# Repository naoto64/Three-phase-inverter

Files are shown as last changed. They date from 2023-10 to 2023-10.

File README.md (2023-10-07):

# Three-phase-inverter
Three-phase inverter operating at AC100V.
Inverter inverter image
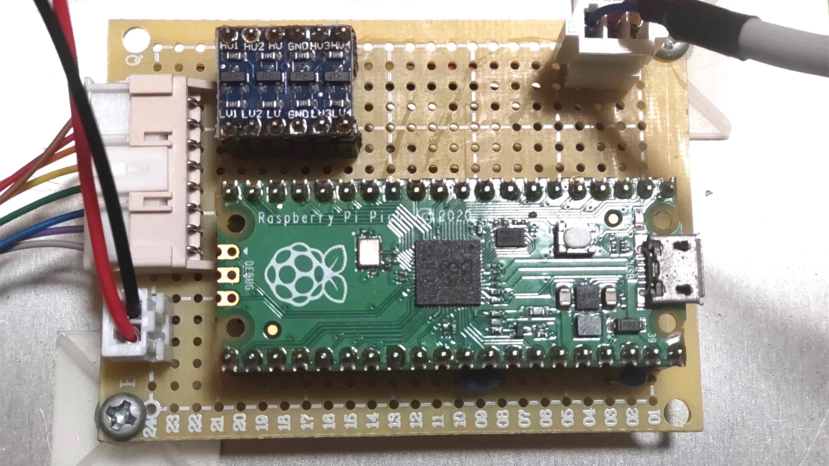
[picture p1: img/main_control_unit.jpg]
Main Control Unit main contorol unit image

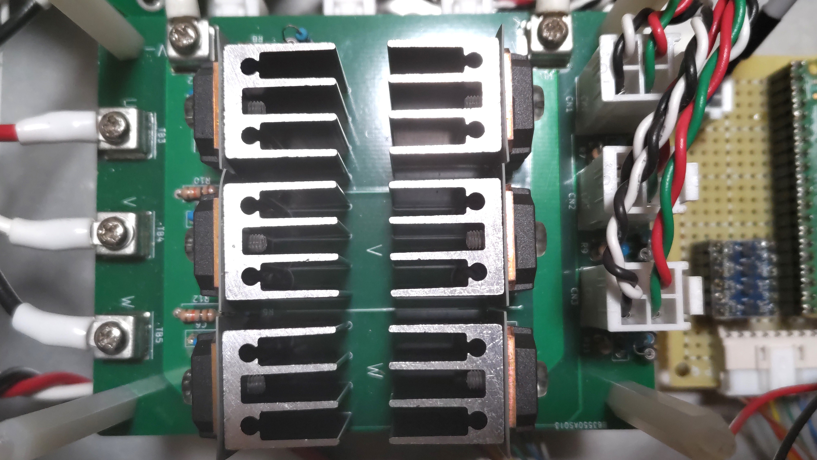
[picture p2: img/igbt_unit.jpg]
IGBT unit igbt unit image

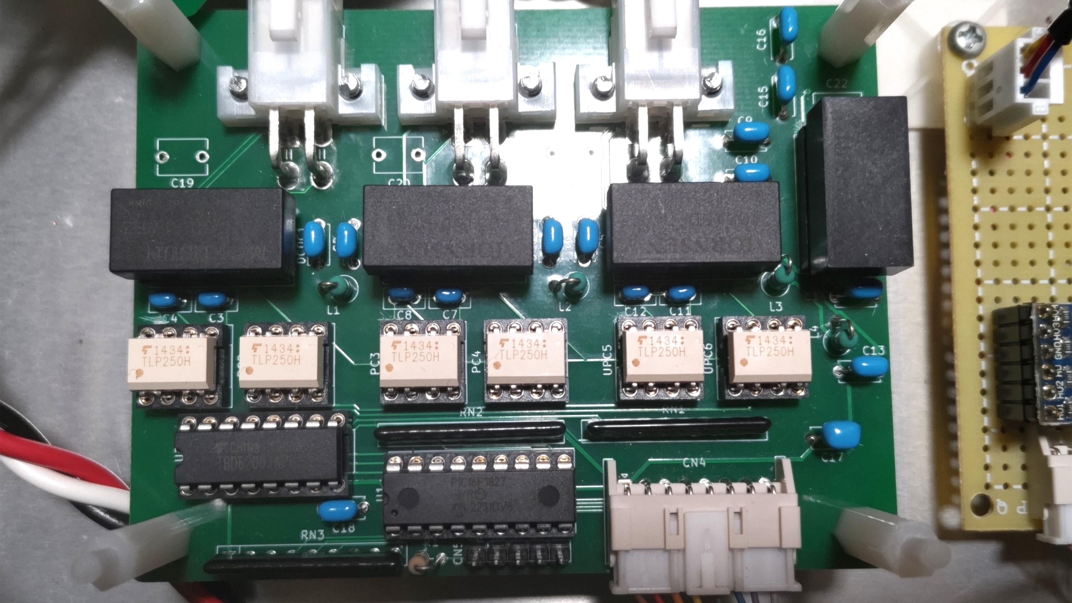
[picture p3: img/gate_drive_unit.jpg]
Gate Drive Unit gate_drive unit image

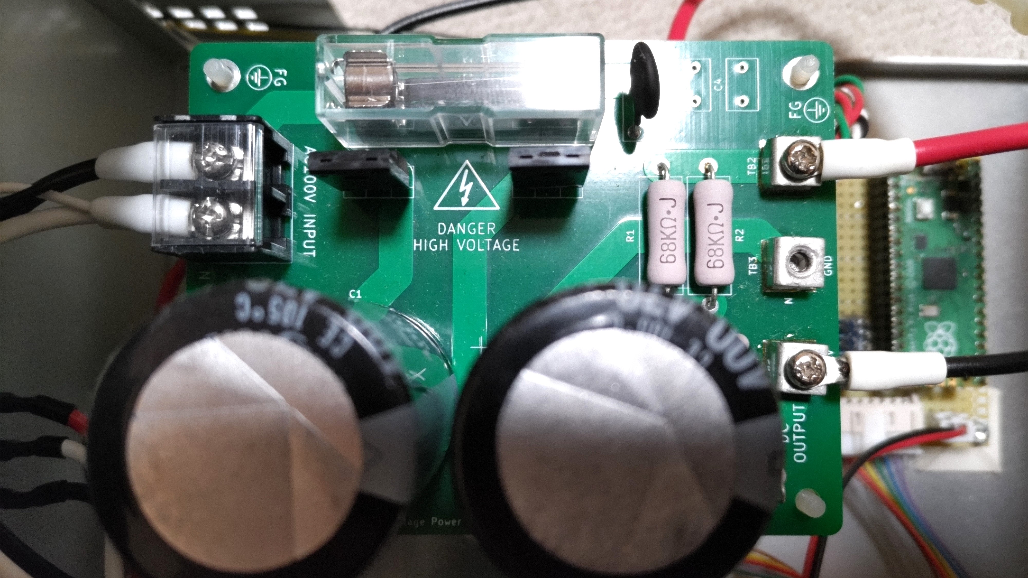
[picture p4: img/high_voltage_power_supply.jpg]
High Voltage Power Supply main contorol unit image


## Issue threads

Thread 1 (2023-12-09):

Change IGBT to other Manufacturer

bca759577, 2023-12-09:
Can I Change IGBT to Toshiba GT50J341?
I compared it and found that the specifications of the two IGBTs are similar.
But the Current Collector of GT50J341 is slightly higher. (GT50J341=50A  RJH60D0DPK=45A)

naoto64, 2023-12-09:
Since it says Dedicated to Current-Resonant Inverter, I cannot recommend it, but I think it can be replaced because the characteristics themselves are almost the same.
However, when replacing, it is necessary to change R1 to R6 of igbt_module to 39Ω.

Closed 2023-12-10.

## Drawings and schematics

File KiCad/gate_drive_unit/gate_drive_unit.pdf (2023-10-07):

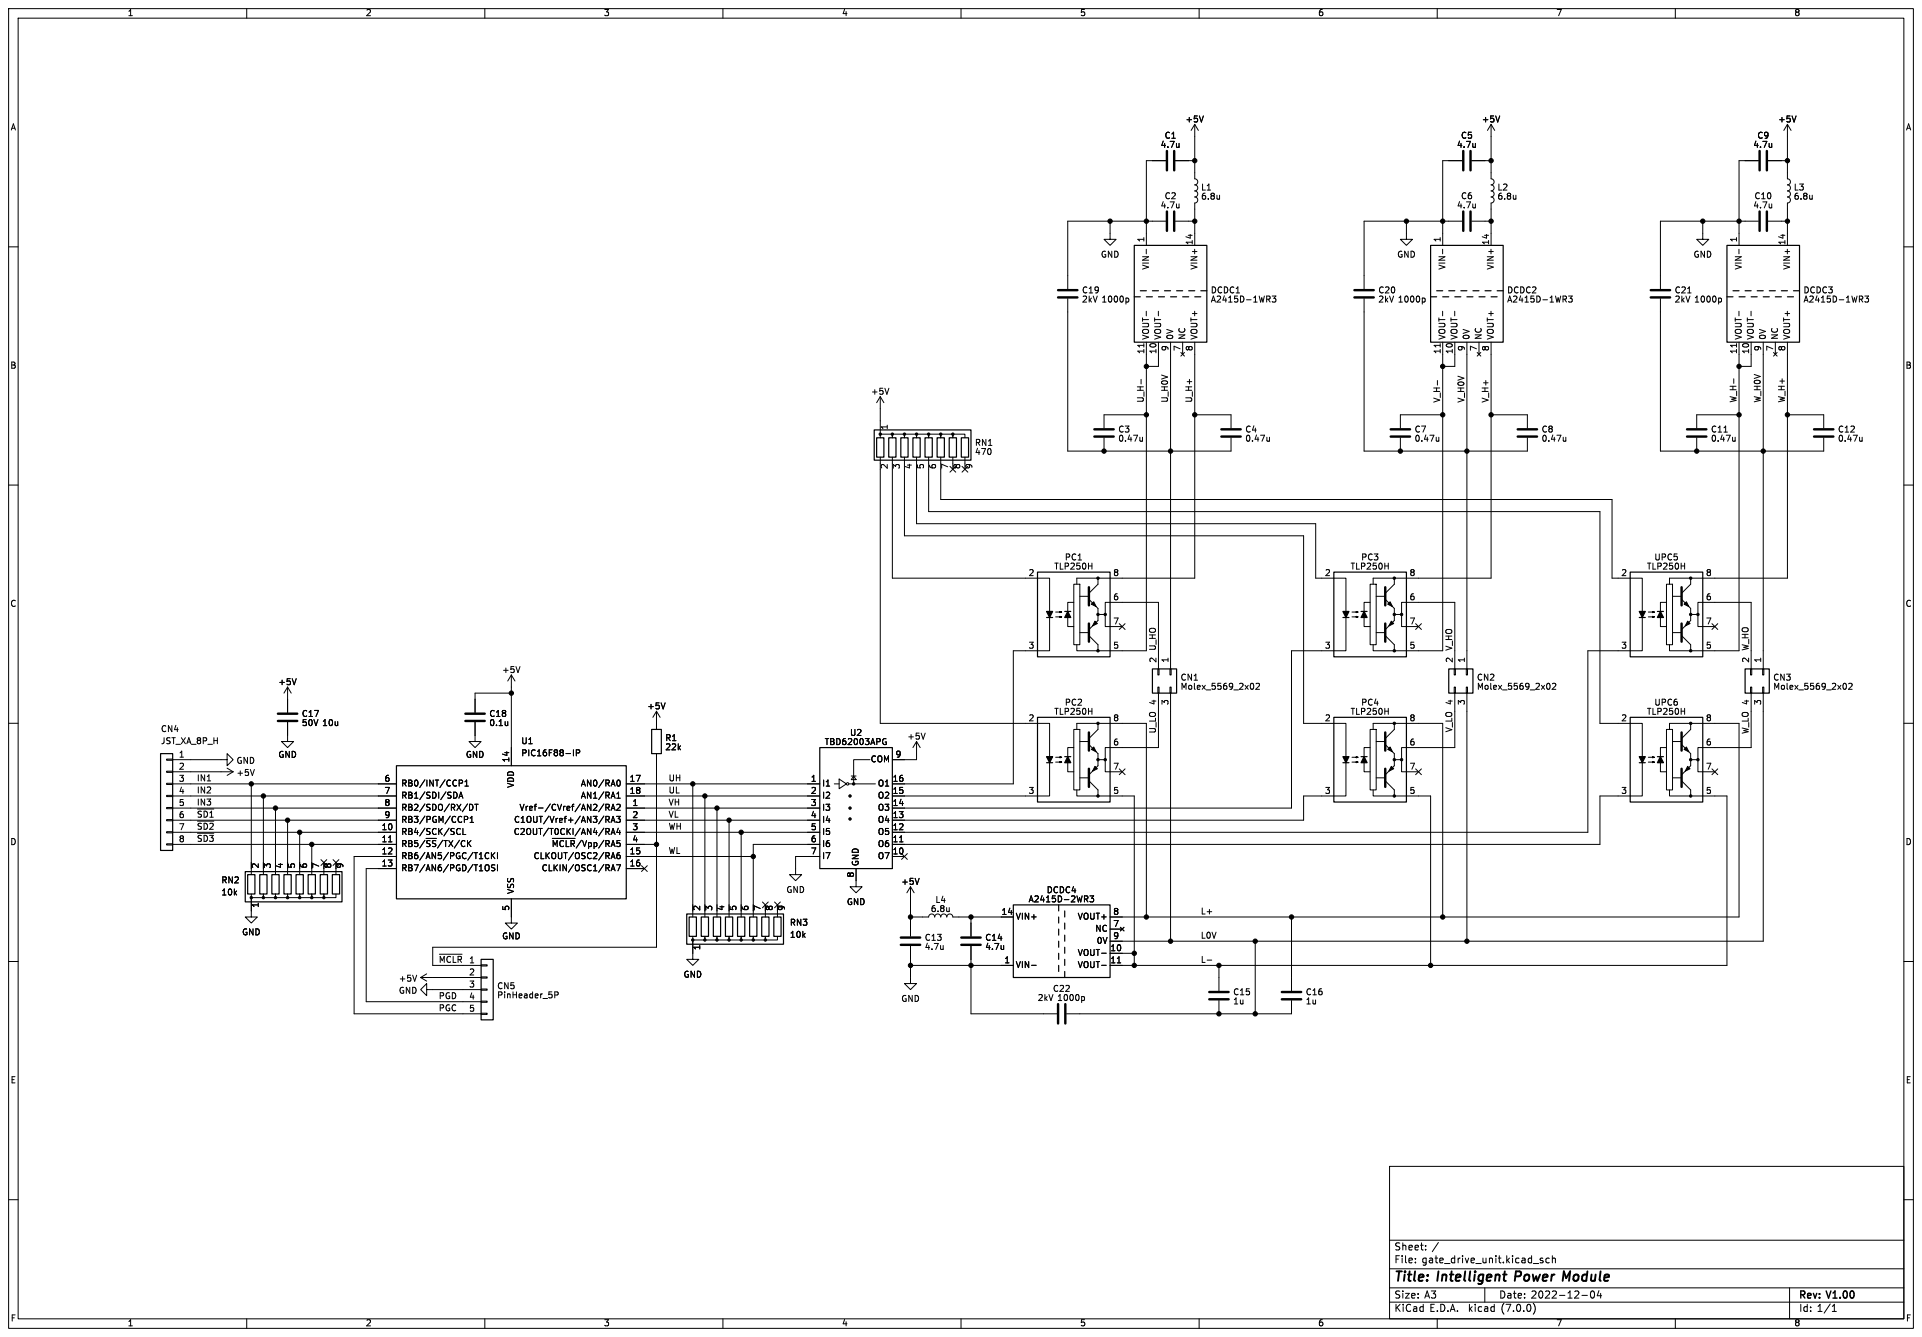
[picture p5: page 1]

3 CN2 Molex_5569_2x02 VIN- 1 VOUT- 10 VOUT- 11 VIN+ 14 NC

5 RB0/INT/CCP1 6 RB1/SDI/SDA 7 RB2/SDO/RX/DT 8 RB3/PGM/CCP1 9 U1PIC16F88-IP U_H0V U_H+ W_H+

5 RB0/INT/CCP1 6 RB1/SDI/SDA 7 RB2/SDO/RX/DT 8 RB3/PGM/CCP1 9 +5V R1

File: gate_drive_unit.kicad_sch Sheet: /
Id: 1/1 Title: Intelligent Power Module

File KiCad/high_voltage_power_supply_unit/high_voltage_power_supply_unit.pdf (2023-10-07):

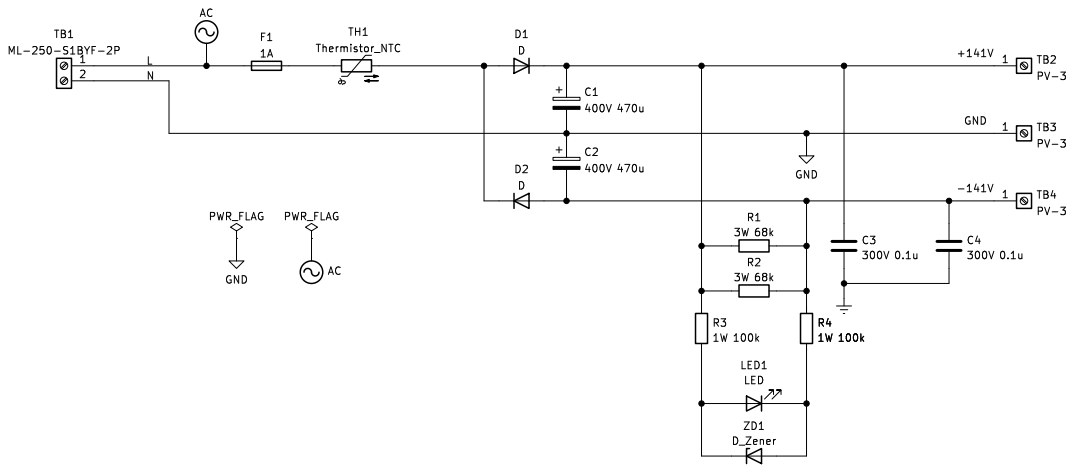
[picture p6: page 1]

Id: 1/1 Title: High Voltage Power Supply Unit File: high_voltage_power_supply_unit.kicad_sch Sheet: / PWR_FLAG

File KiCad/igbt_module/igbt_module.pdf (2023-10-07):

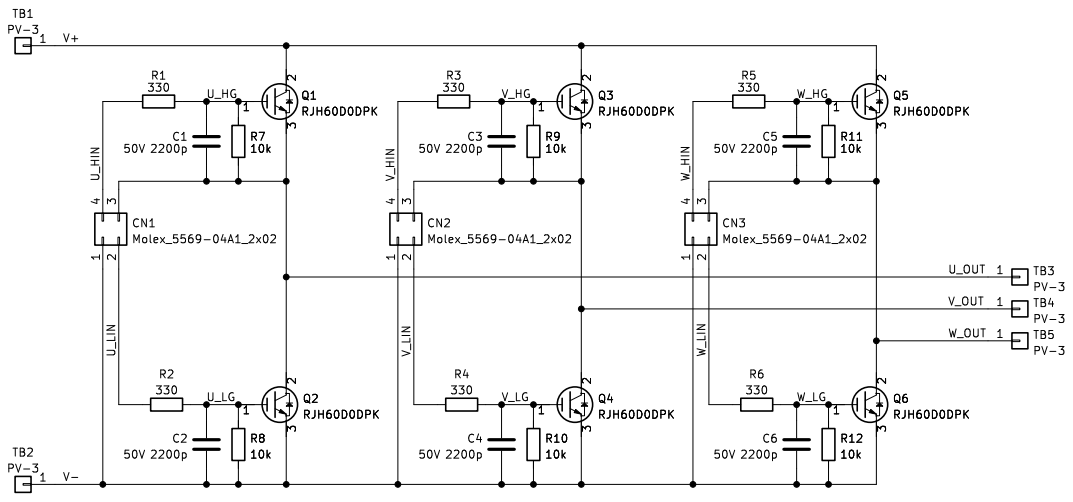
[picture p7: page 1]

Id: 1/1 Title: IGBT Module

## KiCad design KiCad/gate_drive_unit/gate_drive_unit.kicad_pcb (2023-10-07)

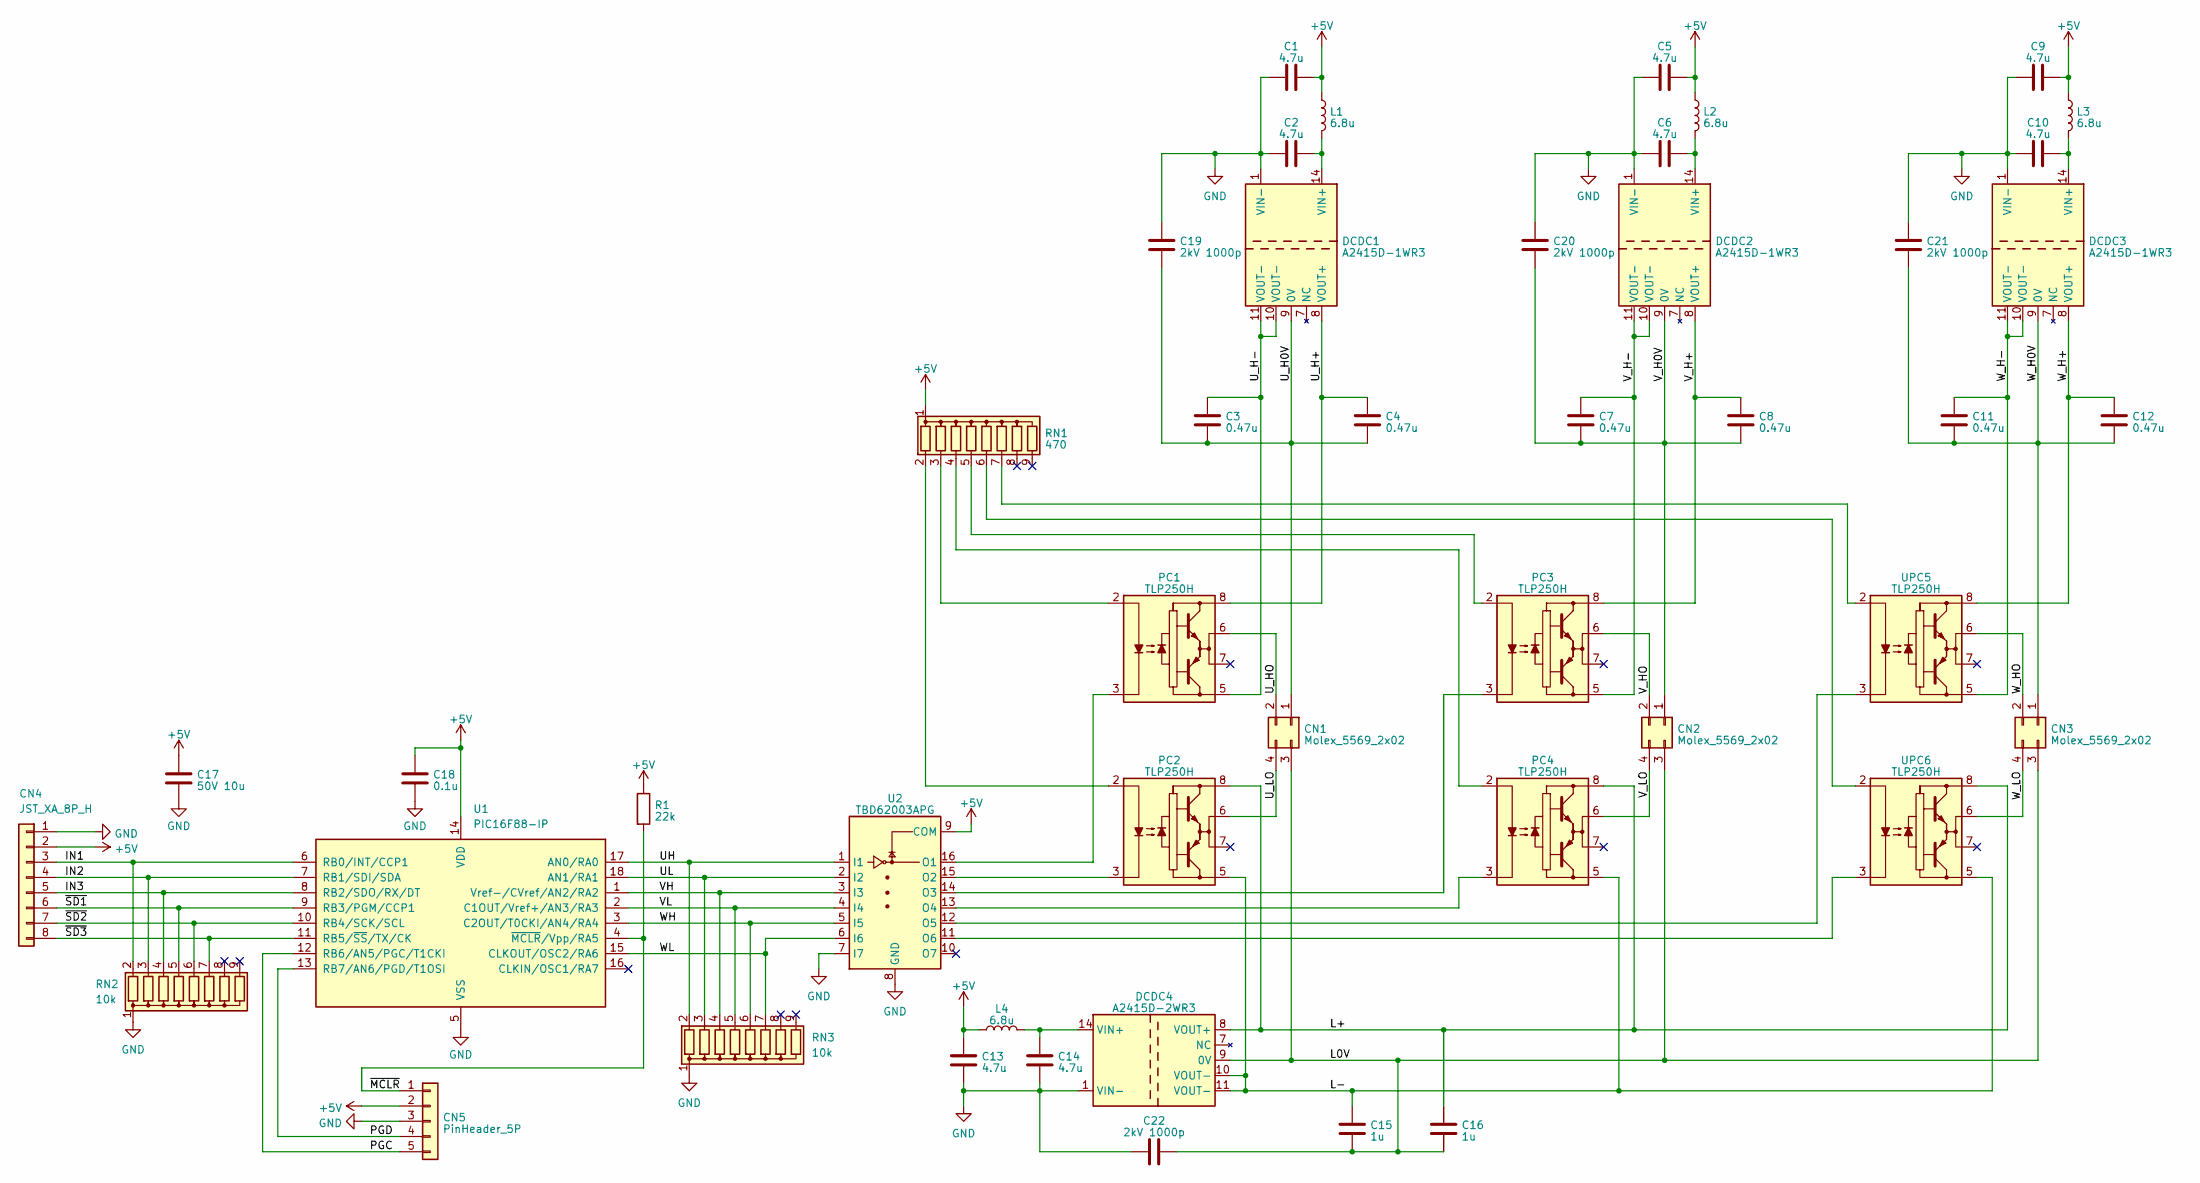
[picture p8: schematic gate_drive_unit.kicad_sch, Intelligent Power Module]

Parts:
C1, C2, C5, C6, C9, C10, C13, C14: 4.7u; C_Disc_D5.0mm_W2.5mm_P5.00mm
C3, C4, C7, C8, C11, C12: 0.47u; C_Disc_D5.0mm_W2.5mm_P2.50mm
C15, C16: 1u; C_Disc_D5.0mm_W2.5mm_P5.00mm
C17: 50V 10u; C_Disc_D5.0mm_W2.5mm_P5.00mm
C18: 0.1u; C_Disc_D5.0mm_W2.5mm_P5.00mm
C19, C20, C21, C22: 2kV 1000p; C_Disc_D6.0mm_W4.4mm_P5.00mm
CN1, CN2, CN3: Molex_5569_2x02; Molex_Mini-Fit_Jr_5569-04A1_2x02_P4.20mm_Horizontal
CN4: JST_XA_8P_H; JST_XA_S08B-XASK-1N-BN_1x08_P2.50mm_Horizontal
CN5: PinHeader_5P; PinHeader_1x05_P2.54mm_Vertical
DCDC1, DCDC2, DCDC3: A2415D-1WR3; DIP-14_W7.62mm_Socket
DCDC4: A2415D-2WR3; DIP-14_W7.62mm_Socket
L1, L2, L3, L4: 6.8u; L_Axial_L7.0mm_D3.3mm_P2.54mm_Vertical_Fastron_MICC
PC1, PC2, PC3, PC4: TLP250H; DIP-8_W7.62mm_Socket
R1: 22k; R_Axial_DIN0204_L3.6mm_D1.6mm_P2.54mm_Vertical
RN1: 470; R_Array_SIP9
RN2, RN3: 10k; R_Array_SIP9
U1: PIC16F88-IP; DIP-18_W7.62mm_Socket
U2: TBD62003APG; DIP-16_W7.62mm
UPC5, UPC6: TLP250H; DIP-8_W7.62mm_Socket

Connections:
+5V: C1.2, C5.2, C9.2, C13.1, C17.1, C18.1, CN4.2, CN5.2, L1.1, L2.1, L3.1, L4.1, R1.1, RN1.1 (common), U1.14 (VDD), U2.9 (COM)
/IN1: CN4.3, RN2.2 (R1), U1.6 (RB0/INT/CCP1)
/IN2: CN4.4, RN2.3 (R2), U1.7 (RB1/SDI/SDA)
/IN3: CN4.5, RN2.4 (R3), U1.8 (RB2/SDO/RX/DT)
/L0V: C15.2, C16.1, C22.1, CN1.3, CN2.3, CN3.3, DCDC4.9 (0V)
/L+: C16.2, DCDC4.8 (VOUT+), PC2.8 (VCC), PC4.8 (VCC), UPC6.8 (VCC)
/L-: C15.1, DCDC4.10 (VOUT-), DCDC4.11 (VOUT-), PC2.5 (VEE), PC4.5 (VEE), UPC6.5 (VEE)
/PGC: CN5.5, U1.12 (RB6/AN5/PGC/T1CKI)
/PGD: CN5.4, U1.13 (RB7/AN6/PGD/T1OSI)
/UH: RN3.2 (R1), U1.17 (AN0/RA0), U2.1 (I1)
/UL: RN3.3 (R2), U1.18 (AN1/RA1), U2.2 (I2)
/U_H0V: C3.2, C4.1, C19.2, CN1.1, DCDC1.9 (0V)
/U_H+: C4.2, DCDC1.8 (VOUT+), PC1.8 (VCC)
/U_H-: C3.1, DCDC1.10 (VOUT-), DCDC1.11 (VOUT-), PC1.5 (VEE)
/U_HO: CN1.2, PC1.6 (VO)
/U_LO: CN1.4, PC2.6 (VO)
/VH: RN3.4 (R3), U1.1 (Vref-/CVref/AN2/RA2), U2.3 (I3)
/VL: RN3.5 (R4), U1.2 (C1OUT/Vref+/AN3/RA3), U2.4 (I4)
/V_H0V: C7.2, C8.1, C20.2, CN2.1, DCDC2.9 (0V)
/V_H+: C8.2, DCDC2.8 (VOUT+), PC3.8 (VCC)
/V_H-: C7.1, DCDC2.10 (VOUT-), DCDC2.11 (VOUT-), PC3.5 (VEE)
/V_HO: CN2.2, PC3.6 (VO)
/V_LO: CN2.4, PC4.6 (VO)
/WH: RN3.6 (R5), U1.3 (C2OUT/T0CKI/AN4/RA4), U2.5 (I5)
/WL: RN3.7 (R6), U1.15 (CLKOUT/OSC2/RA6), U2.6 (I6)
/W_H0V: C11.2, C12.1, C21.2, CN3.1, DCDC3.9 (0V)
/W_H+: C12.2, DCDC3.8 (VOUT+), UPC5.8 (VCC)
/W_H-: C11.1, DCDC3.10 (VOUT-), DCDC3.11 (VOUT-), UPC5.5 (VEE)
/W_HO: CN3.2, UPC5.6 (VO)
/W_LO: CN3.4, UPC6.6 (VO)
/~MCLR: CN5.1, R1.2, U1.4 (~MCLR/Vpp/RA5)
/~SD1: CN4.6, RN2.5 (R4), U1.9 (RB3/PGM/CCP1)
/~SD2: CN4.7, RN2.6 (R5), U1.10 (RB4/SCK/SCL)
/~SD3: CN4.8, RN2.7 (R6), U1.11 (RB5/~SS/TX/CK)
GND: C1.1, C2.1, C5.1, C6.1, C9.1, C10.1, C13.2, C14.2, C17.2, C18.2, C19.1, C20.1, C21.1, C22.2, CN4.1, CN5.3, DCDC1.1 (VIN-), DCDC2.1 (VIN-), DCDC3.1 (VIN-), DCDC4.1 (VIN-), RN2.1 (common), RN3.1 (common), U1.5 (VSS), U2.7 (I7), U2.8 (GND)
unnamed: C2.2, DCDC1.14 (VIN+), L1.2
unnamed: C6.2, DCDC2.14 (VIN+), L2.2
unnamed: C10.2, DCDC3.14 (VIN+), L3.2
unnamed: C14.1, DCDC4.14 (VIN+), L4.2
unnamed: PC1.2 (A), RN1.3 (R2)
unnamed: PC1.3 (C), U2.16 (O1)
unnamed: PC2.2 (A), RN1.2 (R1)
unnamed: PC2.3 (C), U2.15 (O2)
unnamed: PC3.2 (A), RN1.5 (R4)
unnamed: PC3.3 (C), U2.14 (O3)
unnamed: PC4.2 (A), RN1.4 (R3)
unnamed: PC4.3 (C), U2.13 (O4)
unnamed: RN1.6 (R5), UPC6.2 (A)
unnamed: RN1.7 (R6), UPC5.2 (A)
unnamed: U2.12 (O5), UPC5.3 (C)
unnamed: U2.11 (O6), UPC6.3 (C)

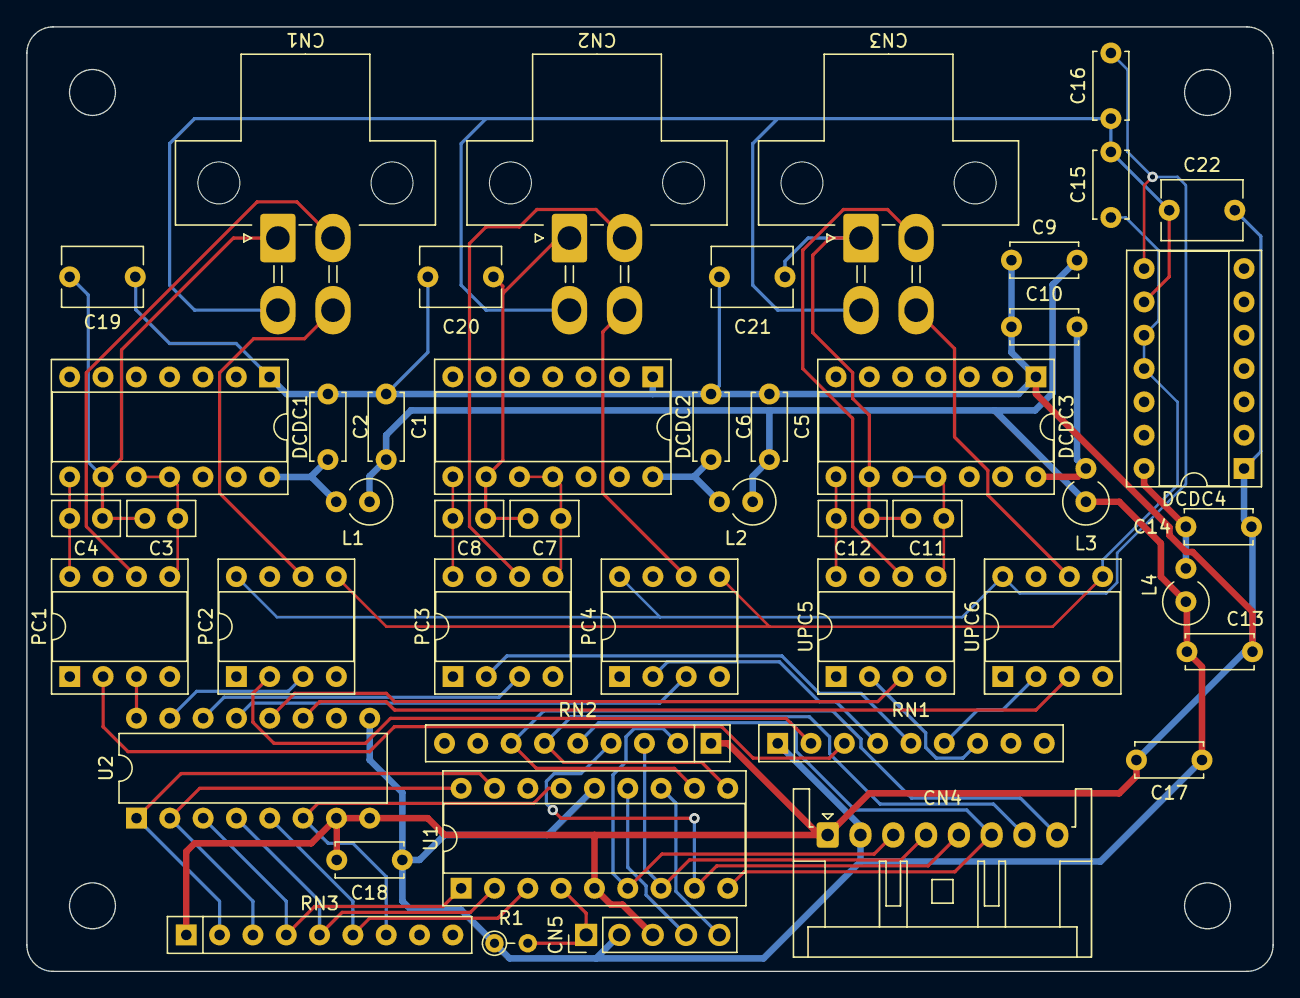
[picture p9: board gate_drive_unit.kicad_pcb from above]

Board: 2 copper layers, 95.0 x 72.0 mm, 47 parts (0 on the bottom side), 51 nets.

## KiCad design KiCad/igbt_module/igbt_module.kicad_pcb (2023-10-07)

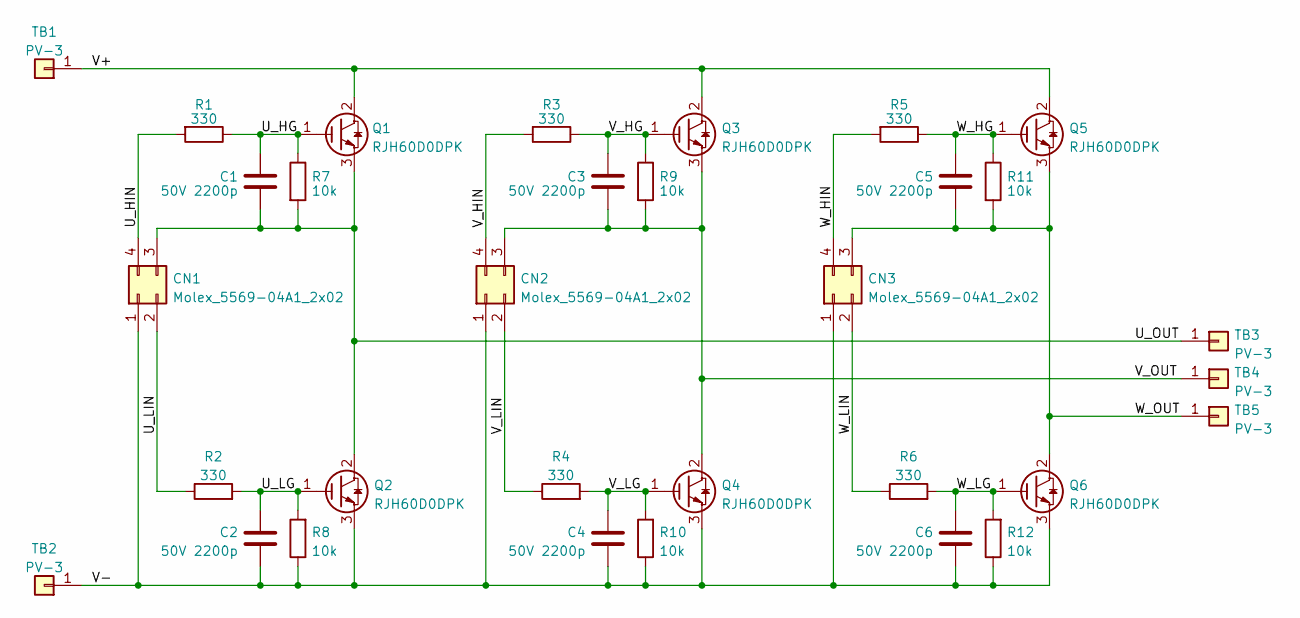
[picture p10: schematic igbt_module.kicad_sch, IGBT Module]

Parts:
C1, C2, C3, C4, C5, C6: 50V 2200p; C_Disc_D5.0mm_W2.5mm_P2.50mm
CN1, CN2, CN3: Molex_5569-04A1_2x02; Molex_Mini-Fit_Jr_5566-04A_2x02_P4.20mm_Vertical
Q1, Q2, Q3, Q4, Q5, Q6: RJH60D0DPK; TO-3P-3_Vertical
R1, R2, R3, R4, R5, R6: 330; R_Axial_DIN0204_L3.6mm_D1.6mm_P2.54mm_Vertical
R7, R9, R11: 10k; R_Axial_DIN0204_L3.6mm_D1.6mm_P2.54mm_Vertical
R8, R10, R12: 10k; R_Axial_DIN0207_L6.3mm_D2.5mm_P7.62mm_Horizontal
TB1, TB2: PV-3
TB3, TB4, TB5: PV-3; PV-3_Both

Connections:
/U_HG: C1.1, Q1.1 (G), R1.1, R7.1
/U_HIN: CN1.4, R1.2
/U_LG: C2.2, Q2.1 (G), R2.2, R8.2
/U_LIN: CN1.2, R2.1
/U_OUT: C1.2, CN1.3, Q1.3 (E), Q2.2 (C), R7.2, TB3.1
/V+: Q1.2 (C), Q3.2 (C), Q5.2 (C), TB1.1
/V-: C2.1, C4.1, C6.1, CN1.1, CN2.1, CN3.1, Q2.3 (E), Q4.3 (E), Q6.3 (E), R8.1, R10.1, R12.1, TB2.1
/V_HG: C3.1, Q3.1 (G), R3.1, R9.1
/V_HIN: CN2.4, R3.2
/V_LG: C4.2, Q4.1 (G), R4.2, R10.2
/V_LIN: CN2.2, R4.1
/V_OUT: C3.2, CN2.3, Q3.3 (E), Q4.2 (C), R9.2, TB4.1
/W_HG: C5.1, Q5.1 (G), R5.1, R11.1
/W_HIN: CN3.4, R5.2
/W_LG: C6.2, Q6.1 (G), R6.2, R12.2
/W_LIN: CN3.2, R6.1
/W_OUT: C5.2, CN3.3, Q5.3 (E), Q6.2 (C), R11.2, TB5.1

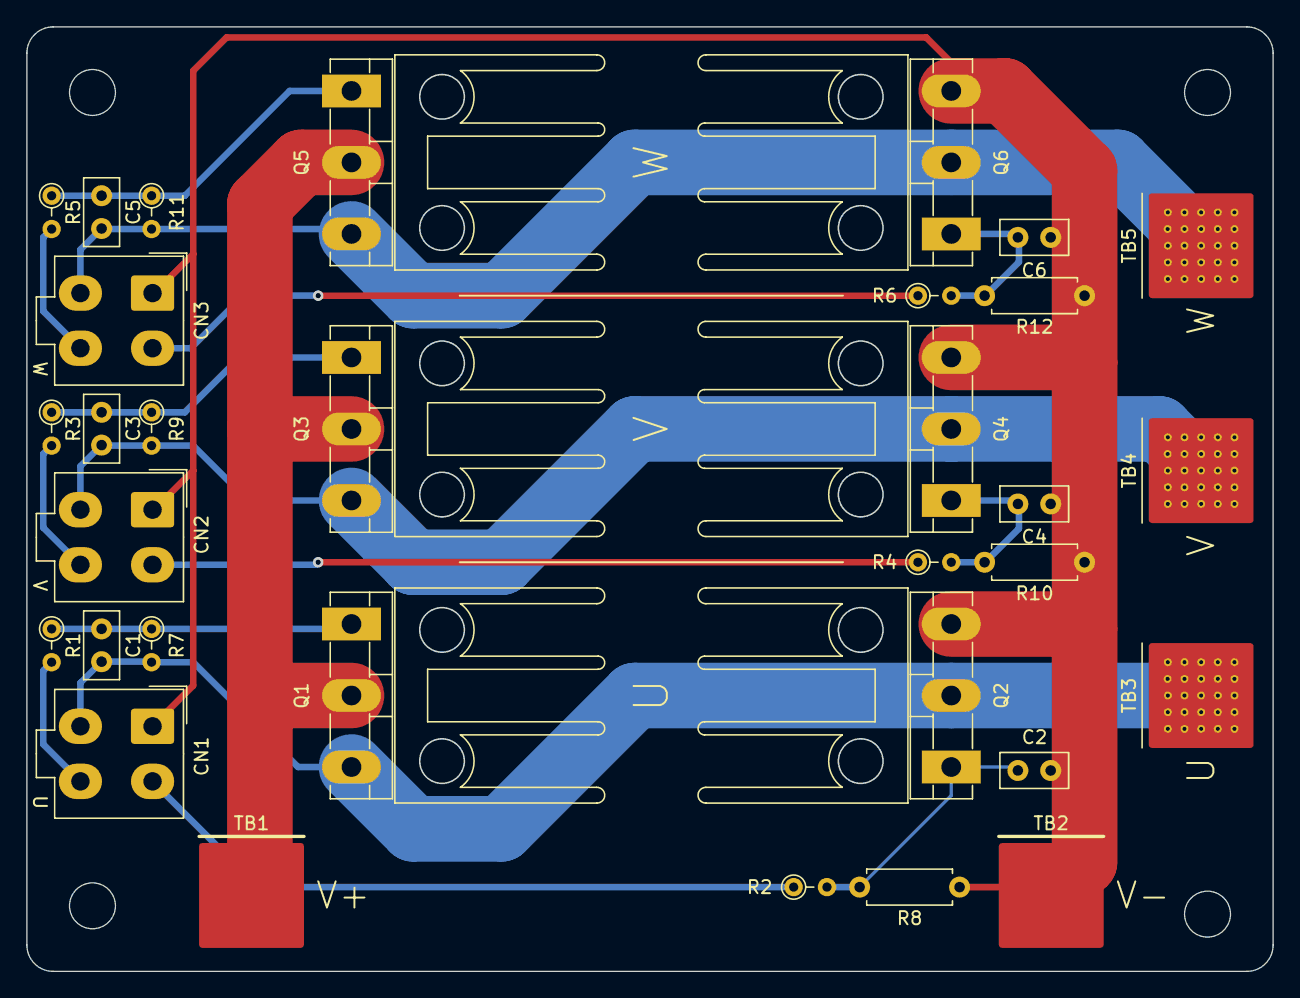
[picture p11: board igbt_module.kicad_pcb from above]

Board: 2 copper layers, 95.0 x 72.0 mm, 32 parts (0 on the bottom side), 17 nets.

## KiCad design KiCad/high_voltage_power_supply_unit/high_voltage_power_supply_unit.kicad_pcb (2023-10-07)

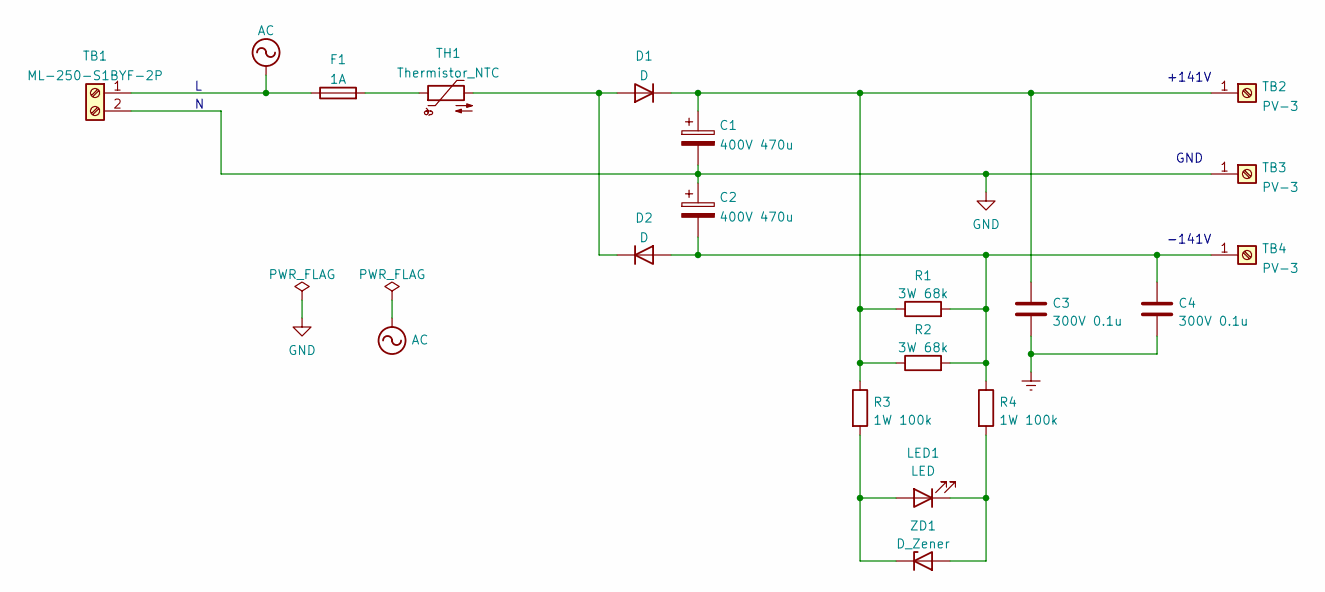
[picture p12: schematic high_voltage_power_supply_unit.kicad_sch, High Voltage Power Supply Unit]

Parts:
C1, C2: 400V 470u; CP_Radial_D30.0mm_P10.00mm_SnapIn
C3, C4: 300V 0.1u; C_Disc_D7.5mm_W4.4mm_P5.00mm
D1, D2: D; TO-220-2_Vertical
F1: 1A; F-200-N
LED1: LED; LED_D3.0mm_Clear
R1, R2: 3W 68k; R_Axial_DIN0617_L17.0mm_D6.0mm_P20.32mm_Horizontal
R3, R4: 1W 100k; R_Axial_DIN0309_L9.0mm_D3.2mm_P5.08mm_Vertical
TB1: ML-250-S1BYF-2P
TB2, TB3, TB4: PV-3
TH1: Thermistor_NTC; C_Rect_L10.0mm_W3.0mm_P7.50mm_MKS4
ZD1: D_Zener; D_DO-34_SOD68_P7.62mm_Horizontal

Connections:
AC: F1.1, TB1.1
Earth: C3.2, C4.2
GND: C1.2, C2.1, TB1.2, TB3.1
unnamed: C1.1, C3.1, D1.1 (K), R1.1, R2.1, R3.1, TB2.1
unnamed: C2.2, C4.1, D2.2 (A), R1.2, R2.2, R4.1, TB4.1
unnamed: D1.2 (A), D2.1 (K), TH1.2
unnamed: F1.2, TH1.1
unnamed: LED1.1 (K), R4.2, ZD1.2 (A)
unnamed: LED1.2 (A), R3.2, ZD1.1 (K)

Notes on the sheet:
GND
+141V
-141V

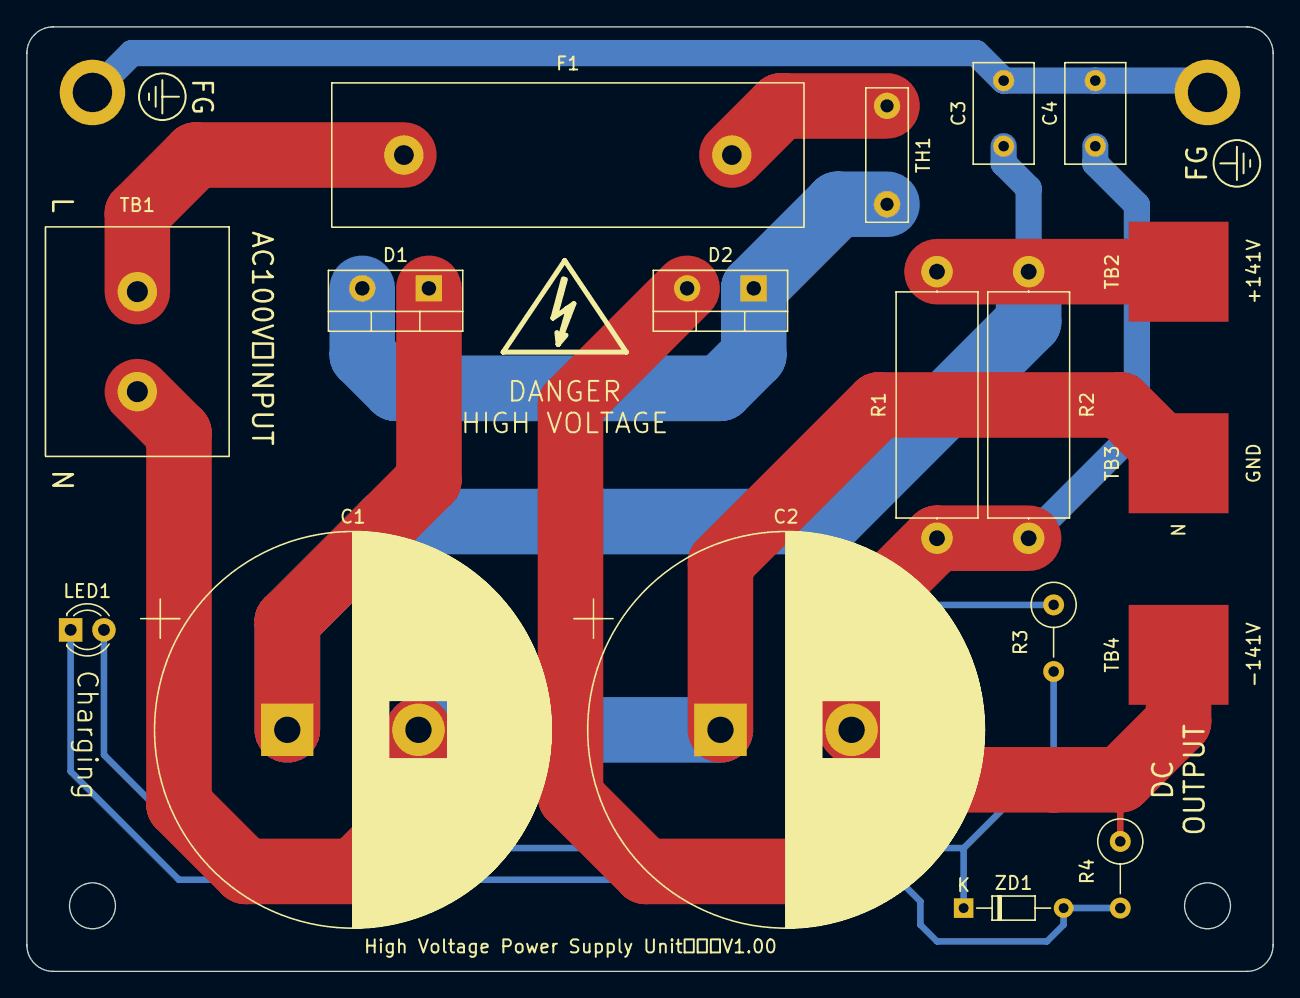
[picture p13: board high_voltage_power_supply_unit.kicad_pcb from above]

Board: 2 copper layers, 95.0 x 72.0 mm, 18 parts (0 on the bottom side), 9 nets.

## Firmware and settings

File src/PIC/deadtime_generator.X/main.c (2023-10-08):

/*
 * File:   main.c
 * Author: naoto
 *
 * Created on 2023/03/25, 18:41
 */


#include <xc.h>

#pragma config FOSC = INTOSC    // 内部クロックを使用
#pragma config PLLEN = ON       // PLLを有効化
#pragma config WDTE = OFF       // ウォッチドッグタイマーは使用しない
#pragma config CP = OFF         // コードプロテクションは無効
#pragma config LVP = OFF        // LVPは使用しない

#define _XTAL_FREQ 32000000
#define IN1 PORTBbits.RB0
#define IN2 PORTBbits.RB1
#define IN3 PORTBbits.RB2
#define SD1 PORTBbits.RB3
#define SD2 PORTBbits.RB4
#define SD3 PORTBbits.RB5
#define DEADTIME 10 // デッドタイム（10us）

#define U_OUT_H LATAbits.LATA0
#define U_OUT_L LATAbits.LATA1
#define V_OUT_H LATAbits.LATA2
#define V_OUT_L LATAbits.LATA3
#define W_OUT_H LATAbits.LATA4
#define W_OUT_L LATAbits.LATA6

void __interrupt() isr(void) {
    if (TMR2IF == 1) {
        // U相
        if (SD1 == 1) { // SD1がHighの場合
            if (IN1 == 1) {    // IN1がHighの場合
                if (U_OUT_L == 1) {   // ローサイド側がONの場合
                    U_OUT_H = 0;
                    U_OUT_L = 0;
                }
                else {
                    U_OUT_H = 1;
                    U_OUT_L = 0;
                }
            }
            else {  // IN1がLowの場合
                if (U_OUT_H == 1) {   // ハイサイド側がONの場合
                    U_OUT_H = 0;
                    U_OUT_L = 0;
                }
                else {
                    U_OUT_H = 0;
                    U_OUT_L = 1;
                }
            }
        }
        else {
            U_OUT_H = 0;
            U_OUT_L = 0;
        }
        
        // V相
        if (SD2 == 1) { // SD2がHighの場合
            if (IN2 == 1) {    // IN2がHighの場合
                if (V_OUT_L == 1) {   // ローサイド側がONの場合
                    V_OUT_H = 0;
                    V_OUT_L = 0;
                }
                else {
                    V_OUT_H = 1;
                    V_OUT_L = 0;
                }
            }
            else {  // IN2がLowの場合
                if (V_OUT_H == 1) {   // ハイサイド側がONの場合
                    V_OUT_H = 0;
                    V_OUT_L = 0;
                }
                else {
                    V_OUT_H = 0;
                    V_OUT_L = 1;
                }
            }
        }
        else {
            V_OUT_H = 0;
            V_OUT_L = 0;
        }
        
        // W相
        if (SD3 == 1) { // SD3がHighの場合
            if (IN3 == 1) {    // IN3がHighの場合
                if (W_OUT_L == 1) {   // ローサイド側がONの場合
                    W_OUT_H = 0;
                    W_OUT_L = 0;
                }
                else {
                    W_OUT_H = 1;
                    W_OUT_L = 0;
                }
            }
            else {  // IN3がLowの場合
                if (W_OUT_H == 1) {   // ハイサイド側がONの場合
                    W_OUT_H = 0;
                    W_OUT_L = 0;
                }
                else {
                    W_OUT_H = 0;
                    W_OUT_L = 1;
                }
            }
        }
        else {
            W_OUT_H = 0;
            W_OUT_L = 0;
        }
        // TMR2割り込みフラグをクリアする
        PIR1bits.TMR2IF = 0;
    }
    return;
}

void main(void) {
    /* ---------- クロック関連処理 ---------- */
    OSCCON = 0b01110000;
    
    /* ---------- IOポートの設定 ---------- */
    ANSELA = 0;         // すべてをデジタルモードに設定
    ANSELB = 0;         // すべてをデジタルモードに設定
    TRISA = 0b00000000; // RA0～RA7を出力に設定
    TRISB = 0b00111111; // RB0～RB5を入力に設定（RB6～7は出力に設定）
    LATA = 0b00000000;  // ポートAをすべてLowに設定
    
    /* ---------- 割り込み関連設定 ---------- */
    T2CON = 0b00000100; // TMR2プリスケーラ値を1倍、ポストスケーラ値は1:1の設定
    PR2 = 32 / 4 * DEADTIME - 1;    // タイマーのカウント値を設定 (32MHz / 4 * 5us - 1)
    TMR2 = 0;   // タイマー2の初期化
    TMR2IF = 0; // タイマー2割込フラグを0にする
    TMR2IE = 1; // タイマー2割込みを許可する
    PEIE = 1;   // 周辺装置割り込みを許可する
    GIE = 1;    // グローバル割り込みを許可する

    /* ---------- メインループ ---------- */
    while (1) {
    }
    return;
}

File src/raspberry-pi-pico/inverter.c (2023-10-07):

// #include <stdint.h>
// #include "pico/stdlib.h"

// #define CONST_FREQ_ACCL 72057594037    // 周波数の加速定数（2^64 / 10^6 / 2^8）
// #define ARR_LEN 1024            // 波形配列の長さ
// #define PHASE_120_DEG 341       // 120度の位相ずれ（ARR_LEN / 3）
// #define PHASE_240_DEG 682       // 240度の位相ずれ（ARR_LEN / 3 * 2）
// #define GPIO_OUT_XOR 0xD000001C // GPIO XOR出力定数
// #define GPIO_OUT_SET 0xD0000014 // GPIO SET出力定数

// // GPIO関連
// #define GPIO_U 2    // U相の出力信号
// #define GPIO_V 3    // V相の出力信号
// #define GPIO_W 4    // W相の出力信号
// #define GPIO_SD 5   // シャットダウン信号

// #define SEQUENCE_ROW_LEN 64
// #define SEQUENCE_COL_LEN 5

// const int16_t sin_arr[ARR_LEN] = {0, 3, 6, 9, 12, 15, 18, 21, 25, 28, 31, 34, 37, 40, 43, 47, 50, 53, 56, 59, 62, 65, 68, 72, 75, 78, 81, 84, 87, 90, 93, 96, 99, 102, 106, 109, 112, 115, 118, 121, 124, 127, 130, 133, 136, 139, 142, 145, 148, 151, 154, 157, 160, 163, 166, 169, 172, 175, 178, 181, 184, 187, 190, 193, 195, 198, 201, 204, 207, 210, 213, 216, 218, 221, 224, 227, 230, 233, 235, 238, 241, 244, 246, 249, 252, 255, 257, 260, 263, 265, 268, 271, 273, 276, 279, 281, 284, 287, 289, 292, 294, 297, 299, 302, 304, 307, 310, 312, 314, 317, 319, 322, 324, 327, 329, 332, 334, 336, 339, 341, 343, 346, 348, 350, 353, 355, 357, 359, 362, 364, 366, 368, 370, 372, 375, 377, 379, 381, 383, 385, 387, 389, 391, 393, 395, 397, 399, 401, 403, 405, 407, 409, 411, 413, 414, 416, 418, 420, 422, 423, 425, 427, 429, 430, 432, 434, 435, 437, 439, 440, 442, 443, 445, 447, 448, 450, 451, 453, 454, 455, 457, 458, 460, 461, 462, 464, 465, 466, 468, 469, 470, 471, 473, 474, 475, 476, 477, 478, 479, 481, 482, 483, 484, 485, 486, 487, 488, 489, 489, 490, 491, 492, 493, 494, 495, 495, 496, 497, 498, 498, 499, 500, 500, 501, 502, 502, 503, 503, 504, 504, 505, 505, 506, 506, 507, 507, 508, 508, 508, 509, 509, 509, 510, 510, 510, 510, 511, 511, 511, 511, 511, 511, 511, 511, 511, 511, 511, 511, 511, 511, 511, 511, 511, 511, 511, 511, 511, 510, 510, 510, 510, 509, 509, 509, 508, 508, 508, 507, 507, 506, 506, 505, 505, 504, 504, 503, 503, 502, 502, 501, 500, 500, 499, 498, 498, 497, 496, 495, 495, 494, 493, 492, 491, 490, 489, 489, 488, 487, 486, 485, 484, 483, 482, 481, 479, 478, 477, 476, 475, 474, 473, 471, 470, 469, 468, 466, 465, 464, 462, 461, 460, 458, 457, 455, 454, 453, 451, 450, 448, 447, 445, 443, 442, 440, 439, 437, 435, 434, 432, 430, 429, 427, 425, 423, 422, 420, 418, 416, 414, 413, 411, 409, 407, 405, 403, 401, 399, 397, 395, 393, 391, 389, 387, 385, 383, 381, 379, 377, 375, 372, 370, 368, 366, 364, 362, 359, 357, 355, 353, 350, 348, 346, 343, 341, 339, 336, 334, 332, 329, 327, 324, 322, 319, 317, 314, 312, 310, 307, 304, 302, 299, 297, 294, 292, 289, 287, 284, 281, 279, 276, 273, 271, 268, 265, 263, 260, 257, 255, 252, 249, 246, 244, 241, 238, 235, 233, 230, 227, 224, 221, 218, 216, 213, 210, 207, 204, 201, 198, 195, 193, 190, 187, 184, 181, 178, 175, 172, 169, 166, 163, 160, 157, 154, 151, 148, 145, 142, 139, 136, 133, 130, 127, 124, 121, 118, 115, 112, 109, 106, 102, 99, 96, 93, 90, 87, 84, 81, 78, 75, 72, 68, 65, 62, 59, 56, 53, 50, 47, 43, 40, 37, 34, 31, 28, 25, 21, 18, 15, 12, 9, 6, 3, 0, -4, -7, -10, -13, -16, -19, -22, -26, -29, -32, -35, -38, -41, -44, -48, -51, -54, -57, -60, -63, -66, -69, -73, -76, -79, -82, -85, -88, -91, -94, -97, -100, -103, -107, -110, -113, -116, -119, -122, -125, -128, -131, -134, -137, -140, -143, -146, -149, -152, -155, -158, -161, -164, -167, -170, -173, -176, -179, -182, -185, -188, -191, -194, -196, -199, -202, -205, -208, -211, -214, -217, -219, -222, -225, -228, -231, -234, -236, -239, -242, -245, -247, -250, -253, -256, -258, -261, -264, -266, -269, -272, -274, -277, -280, -282, -285, -288, -290, -293, -295, -298, -300, -303, -305, -308, -311, -313, -315, -318, -320, -323, -325, -328, -330, -333, -335, -337, -340, -342, -344, -347, -349, -351, -354, -356, -358, -360, -363, -365, -367, -369, -371, -373, -376, -378, -380, -382, -384, -386, -388, -390, -392, -394, -396, -398, -400, -402, -404, -406, -408, -410, -412, -414, -415, -417, -419, -421, -423, -424, -426, -428, -430, -431, -433, -435, -436, -438, -440, -441, -443, -444, -446, -448, -449, -451, -452, -454, -455, -456, -458, -459, -461, -462, -463, -465, -466, -467, -469, -470, -471, -472, -474, -475, -476, -477, -478, -479, -480, -482, -483, -484, -485, -486, -487, -488, -489, -490, -490, -491, -492, -493, -494, -495, -496, -496, -497, -498, -499, -499, -500, -501, -501, -502, -503, -503, -504, -504, -505, -505, -506, -506, -507, -507, -508, -508, -509, -509, -509, -510, -510, -510, -511, -511, -511, -511, -512, -512, -512, -512, -512, -512, -512, -512, -512, -512, -512, -512, -512, -512, -512, -512, -512, -512, -512, -512, -512, -511, -511, -511, -511, -510, -510, -510, -509, -509, -509, -508, -508, -507, -507, -506, -506, -505, -505, -504, -504, -503, -503, -502, -501, -501, -500, -499, -499, -498, -497, -496, -496, -495, -494, -493, -492, -491, -490, -490, -489, -488, -487, -486, -485, -484, -483, -482, -480, -479, -478, -477, -476, -475, -474, -472, -471, -470, -469, -467, -466, -465, -463, -462, -461, -459, -458, -456, -455, -454, -452, -451, -449, -448, -446, -444, -443, -441, -440, -438, -436, -435, -433, -431, -430, -428, -426, -424, -423, -421, -419, -417, -415, -414, -412, -410, -408, -406, -404, -402, -400, -398, -396, -394, -392, -390, -388, -386, -384, -382, -380, -378, -376, -373, -371, -369, -367, -365, -363, -360, -358, -356, -354, -351, -349, -347, -344, -342, -340, -337, -335, -333, -330, -328, -325, -323, -320, -318, -315, -313, -311, -308, -305, -303, -300, -298, -295, -293, -290, -288, -285, -282, -280, -277, -274, -272, -269, -266, -264, -261, -258, -256, -253, -250, -247, -245, -242, -239, -236, -234, -231, -228, -225, -222, -219, -217, -214, -211, -208, -205, -202, -199, -196, -194, -191, -188, -185, -182, -179, -176, -173, -170, -167, -164, -161, -158, -155, -152, -149, -146, -143, -140, -137, -134, -131, -128, -125, -122, -119, -116, -113, -110, -107, -103, -100, -97, -94, -91, -88, -85, -82, -79, -76, -73, -69, -66, -63, -60, -57, -54, -51, -48, -44, -41, -38, -35, -32, -29, -26, -22, -19, -16, -13, -10, -7, -4}; // 正弦波
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

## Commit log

2022-03-24 Added KiCad schematic.
    First upload
    [Three-phase-inverter.kicad_sch, power-unit.kicad_sch]
2022-03-26 Creating a program for the ESP32.
    Creating a VVVF control program.
2023-10-07 Update KiCad schematic data.
    [gate_drive_unit.kicad_pcb, gate_drive_unit.kicad_sch, high_voltage_power_supply_unit.kicad_pcb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]
